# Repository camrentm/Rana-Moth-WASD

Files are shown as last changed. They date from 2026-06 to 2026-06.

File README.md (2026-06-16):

# The Rana Labs Moth (WASD Version)

WASD version of [Rana Labs'](https://github.com/rana-sylvatica) Moth, a foldable leverless controller.

<div style="display: flex; gap: 10px;">
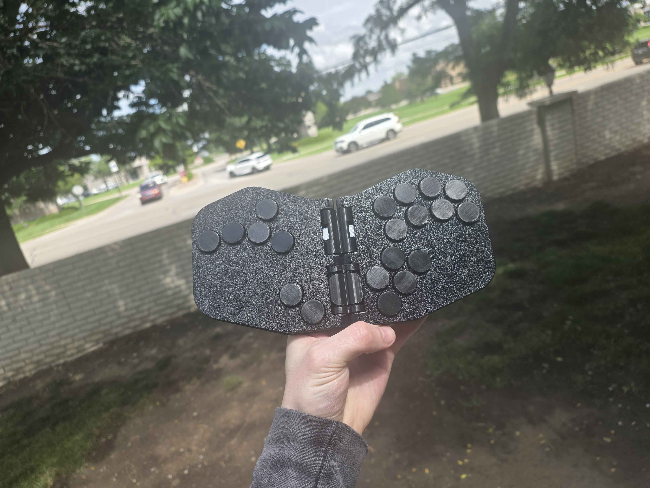
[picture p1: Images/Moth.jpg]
Moth open
    
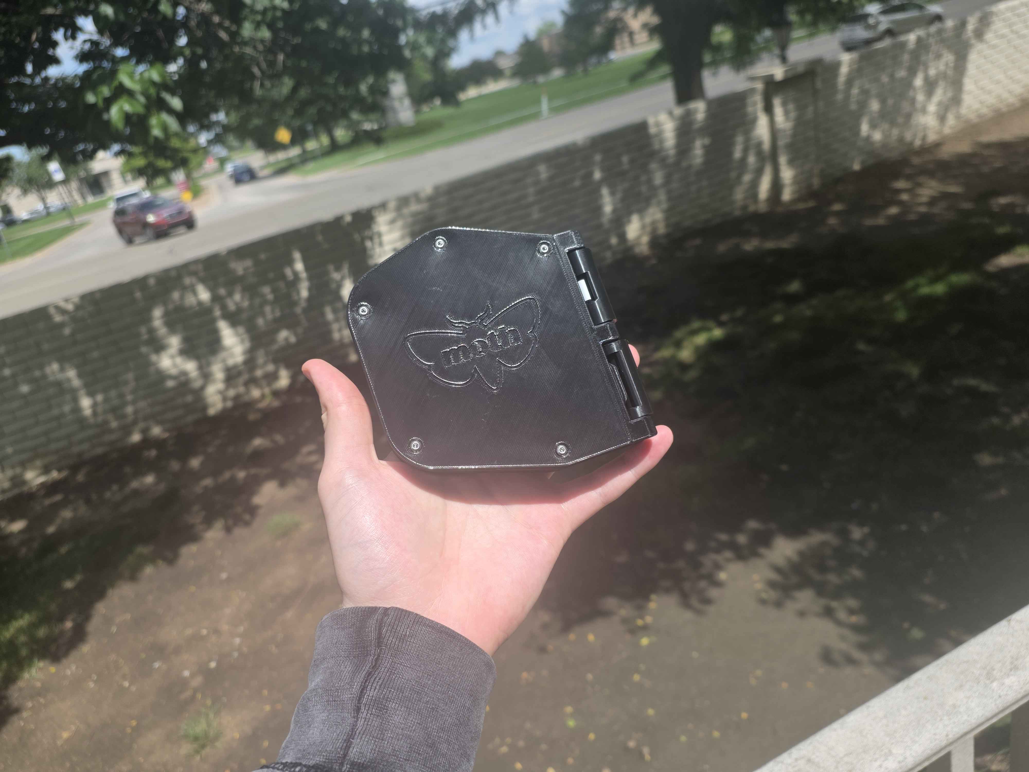
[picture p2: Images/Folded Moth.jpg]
Moth folded
    
</div>

---

## Components

I printed the entire shell and hinges in **Bambu Lab Matte PLA** (any PLA should work, though build quality feel may vary).

- **Mainboard:** RP2040 integrated directly onto the left custom PCB. The right side connects via ribbon cable.
- **Switches:** Any Kailh Choc low-profile switch. Must be low-profile (standard height switches won't fit).
- **USB-C:** [QuRB](https://github.com/rana-sylvatica/rana-tadpole/tree/main/PCBs/Breakout%20Board%20(QuRB)) by [Quark Works](https://github.com/quark-works) and Rana Labs, a USB-C breakout board with a ribbon cable port for solderless assembly.
- **Hardware:** M2 and M3 screws only. You'll need ten M3 heat inserts for the backplates, twelve M3×5/6mm bolts for the backplates and QuRB, and eight M2×4mm bolts for the mainboards.

---

## Assembly

The custom PCB eliminates all handwiring. The only soldering required is installing the hotswap sockets for the Choc switches.

The two halves connect via a 20-pin 0.5mm pitch ribbon cable. The QuRB connects to the left board via a 12-pin 0.5mm pitch ribbon cable for the USB-C port.

---

## Firmware

This build runs a custom fork of HayBox configured for the Moth layout. Find it at [camrentm/HayBox-Rana-Moth](https://github.com/camrentm/HayBox-Rana-Moth).

---

## Magnets

Strong magnets are essential since they're working against the spring force of every switch.

- **Size:** 6×3mm Neodymium, stacked 2 high per hole
- **Count:** 10 holes × 2 magnets = **20 magnets total**

The snap when closing is very satisfying and holds the Moth securely folded.

---

## Prism Ergonomic Mode

In the reverse-folded position, a lip on each hinge piece stops the wings from overfolding and creates a clean resting angle. The rounded hinge backs add friction to keep the Moth rigid in this position.

You can edit the lip width in the hinge model to adjust the fold angle to your preference.

---

## Notes

- **Button fit:** Buttons must sit flush with the face when depressed, or the halves won't close cleanly. Strong magnets may compensate for minor protrusion.
- **Hinge pin slot:** Left open in this design. The friction fit holds without caps, and it makes intentional pin removal much easier.

---

## Files

| Folder | Contents |
|---|---|
| `Shell/` | Top panels and backplates (STEP) |
| `Hinge and Buttons/` | Hinge upper/lower, hinge pin, and keycap models (STEP) |
| `Moth PCB/` | KiCad PCB project, schematics, and fabrication files |
| `DXF/` | PCB outlines and hole patterns |
| `Images/` | Build photos |

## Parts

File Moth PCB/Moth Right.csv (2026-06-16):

Designator | Footprint | Quantity | Value | LCSC Part #
J5 | XUNPU FPC-05F-20PH20 | 1 | FPC-05F-20PH20 | C2856803

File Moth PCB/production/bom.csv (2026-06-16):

Designator | Footprint | Quantity | Value | LCSC Part #
A | SW_Hotswap_Kailh_Choc_V1V2_THT | 1 | A
B | SW_Hotswap_Kailh_Choc_V1V2_THT | 1 | B
C1, C10, C2, C4 | 0402 | 4 | 1uF | C52923
C11, C12, C13, C14, C15, C16, C17, C3, C5, C6 | 0402 | 10 | 100nF | C1525
C7, C8 | 0402 | 2 | 22pF | C1555
C9 | 0402 | 1 | 10uF | C15525
C_DOWN | SW_Hotswap_Kailh_Choc_V1V2_THT | 1 | C Down
C_LEFT | SW_Hotswap_Kailh_Choc_V1V2_THT | 1 | C Left
C_RIGHT | SW_Hotswap_Kailh_Choc_V1V2_THT | 1 | C Right
C_UP | SW_Hotswap_Kailh_Choc_V1V2_THT | 1 | C Up
D1 | D_SOD-123 | 1 | Schottky Diode | C8598
D3 | 0805 | 1 | GREEN | C84256
DOWN | SW_Hotswap_Kailh_Choc_V1V2_THT | 1 | Down
J4 | FPC-05F-30PH20 | 1 | Left Ribbon
J5 | FPC-05F-30PH20 | 1 | Right Ribbon
L | SW_Hotswap_Kailh_Choc_V1V2_THT | 1 | L
LEFT | SW_Hotswap_Kailh_Choc_V1V2_THT | 1 | Left
LS | SW_Hotswap_Kailh_Choc_V1V2_THT | 1 | LS
MS | SW_Hotswap_Kailh_Choc_V1V2_THT | 1 | MS
MX | SW_Hotswap_Kailh_Choc_V1V2_THT | 1 | MX
MY | SW_Hotswap_Kailh_Choc_V1V2_THT | 1 | MY
R | SW_Hotswap_Kailh_Choc_V1V2_THT | 1 | R
R10, R11 | 0402 | 2 | 1k | C11702
R4 | 0402 | 1 | 470 | C25117
R5 | 0603 | 1 | 5.6k | C23189
R6 | 0603 | 1 | 10k | C25804
R7 | 0402 | 1 | 10k | C25744
R8, R9 | 0603 | 2 | 27 | C25190
RIGHT | SW_Hotswap_Kailh_Choc_V1V2_THT | 1 | Right
START | SW_Hotswap_Kailh_Choc_V1V2_THT | 1 | Start
SW1 | SW_SPST_SKQG_WithStem | 1 | Boot | C202424
U1 | SOT-23 | 1 | XC6206 | C5446
U2 | FPC-SMD_X05A26H12G | 1 | X05A26H12G | C519263
U3 | RP2040-QFN-56 | 1 | RP2040 | C2040
U4 | SOIC-8_5.23x5.23mm_P1.27mm | 1 | W25Q128JVS | C97521
UP | SW_Hotswap_Kailh_Choc_V1V2_THT | 1 | Up
X | SW_Hotswap_Kailh_Choc_V1V2_THT | 1 | X
Y | SW_Hotswap_Kailh_Choc_V1V2_THT | 1 | Y
Y1 | Crystal_SMD_3225-4Pin_3.2x2.5mm | 1 | 12MHz | C9002
Z | SW_Hotswap_Kailh_Choc_V1V2_THT | 1 | Z

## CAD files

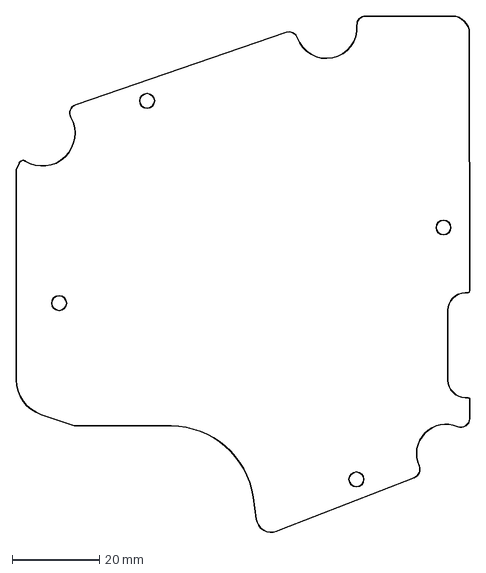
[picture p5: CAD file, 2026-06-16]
DXF/Reworked Left PCB.dxf
104.0 x 118.5 mm

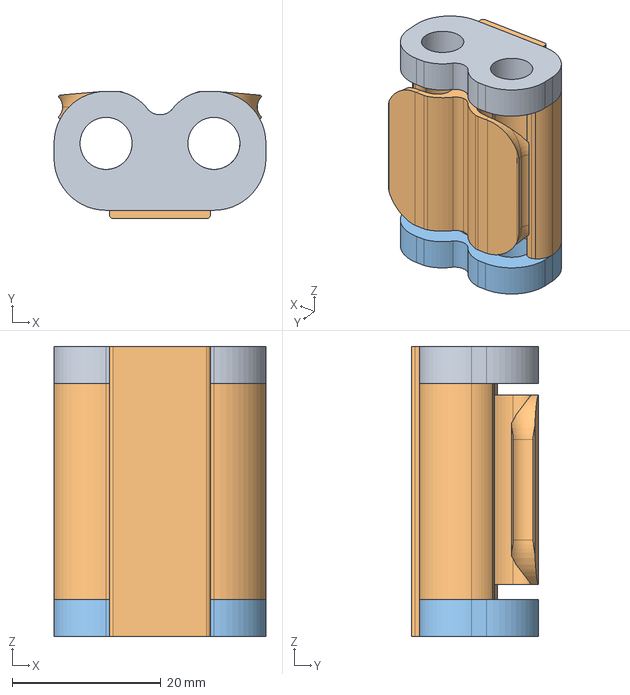
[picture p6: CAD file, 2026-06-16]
Hinge and Buttons/Hinge Lower.step
28.5 x 17.1 x 39.0 mm

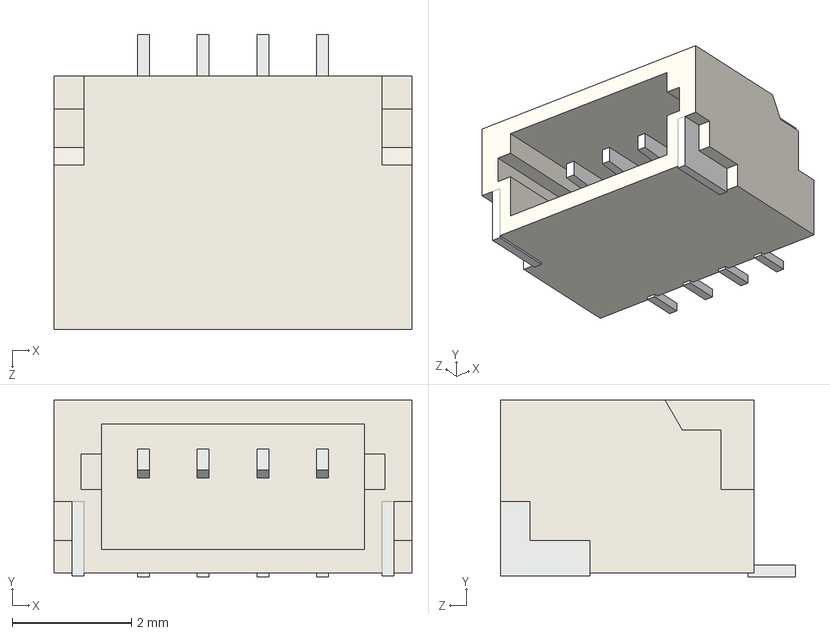
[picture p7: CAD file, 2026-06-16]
Moth PCB/qw-footprints/qw-footprints/JST-SM04B-SRSS-TB.STEP
6.00 x 2.96 x 4.95 mm

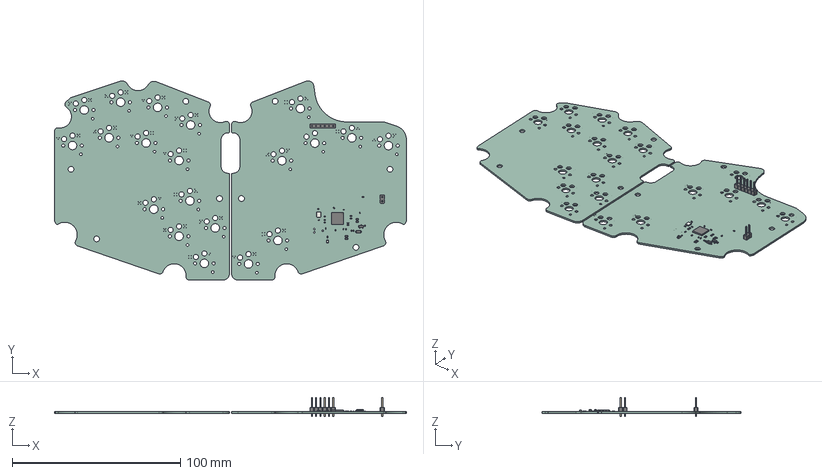
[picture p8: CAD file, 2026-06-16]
Moth PCB/Rana Tadpole PCB.step
209.1 x 118.4 x 11.5 mm
C_0402_1005Metric x 17
R_0603_1608Metric x 4
R_0402_1005Metric x 4
SOT_23
QFN-56-1EP_7x7mm_Pitch0.4mm
D_SOD_123
PinHeader_1x02_P254mm_Vertical
PinHeader_1x06_P254mm_Vertical
LED_0805_2012Metric
Crystal_SMD_3225-4Pin_3.2x2.5mm
Moth_PCB_1
Moth_PCB_2

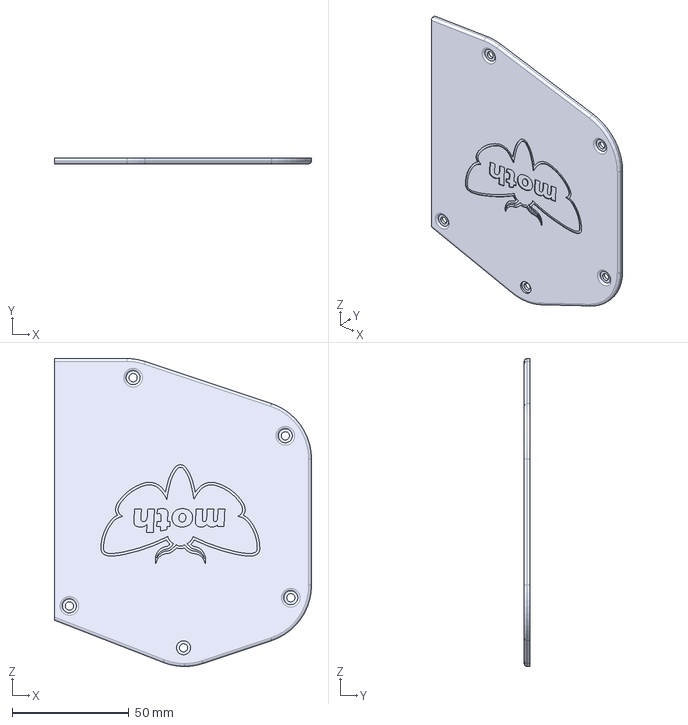
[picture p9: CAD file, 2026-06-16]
Shell/Moth Backplate Left.step
110.0 x 2.40 x 131.8 mm

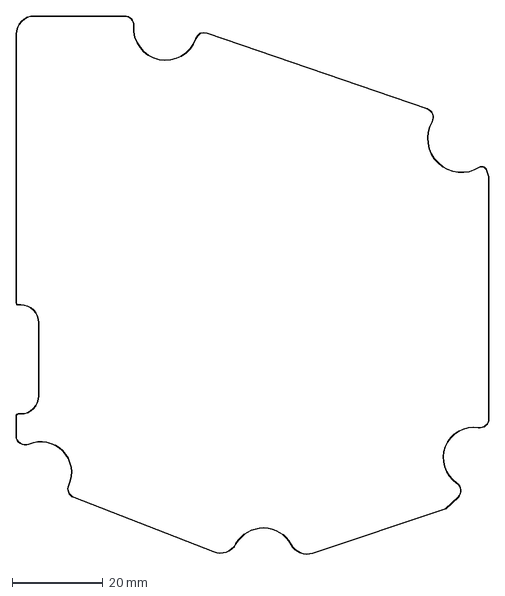
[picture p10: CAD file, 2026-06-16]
DXF/Right PCB.dxf
104.0 x 118.7 mm

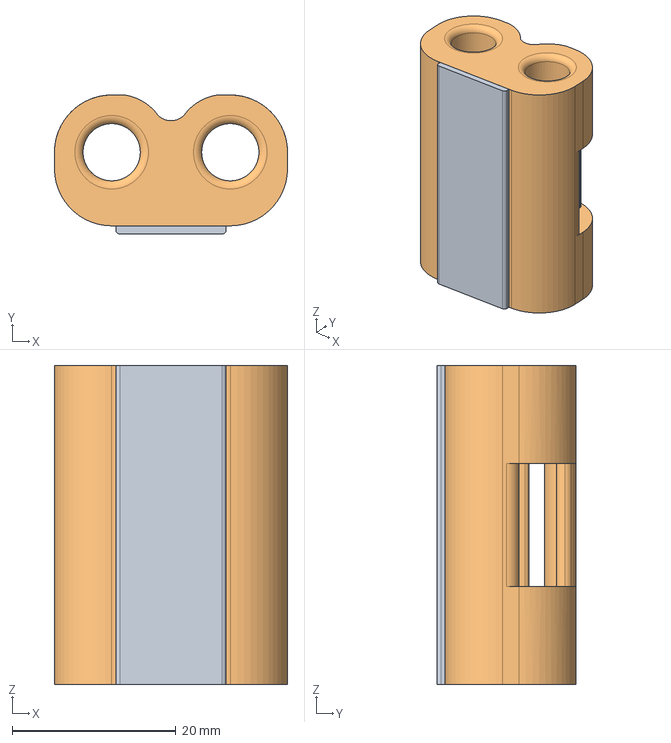
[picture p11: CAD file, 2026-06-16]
Hinge and Buttons/Hinge Upper.step
28.5 x 17.0 x 39.0 mm

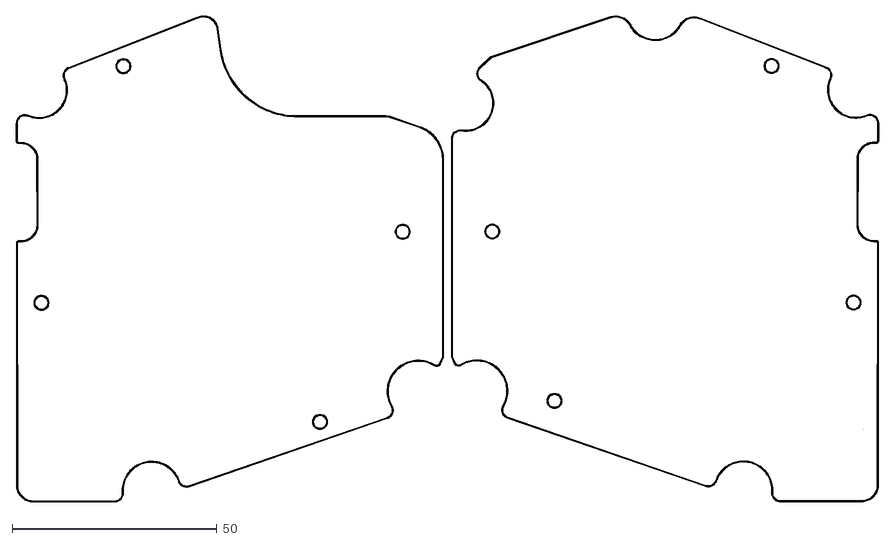
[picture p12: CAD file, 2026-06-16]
Moth PCB/Moth-Edge_Cuts.dxf
210.4 x 118.6

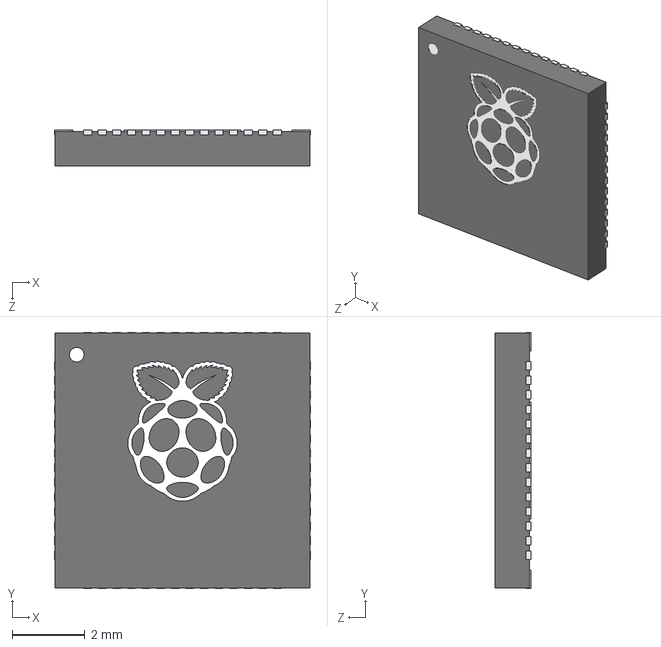
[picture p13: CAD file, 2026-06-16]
Moth PCB/qw-footprints/qw-footprints/RP2040_QFN_PACKAGE.STEP
7.02 x 7.02 x 1.00 mm

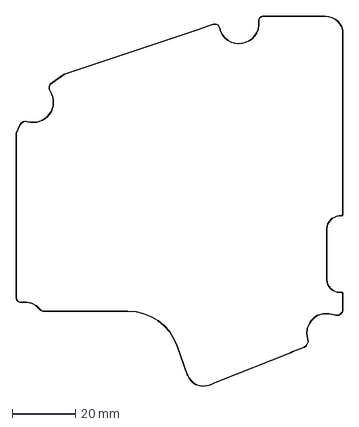
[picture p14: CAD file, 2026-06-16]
DXF/Left PCB.dxf
103.0 x 116.8 mm

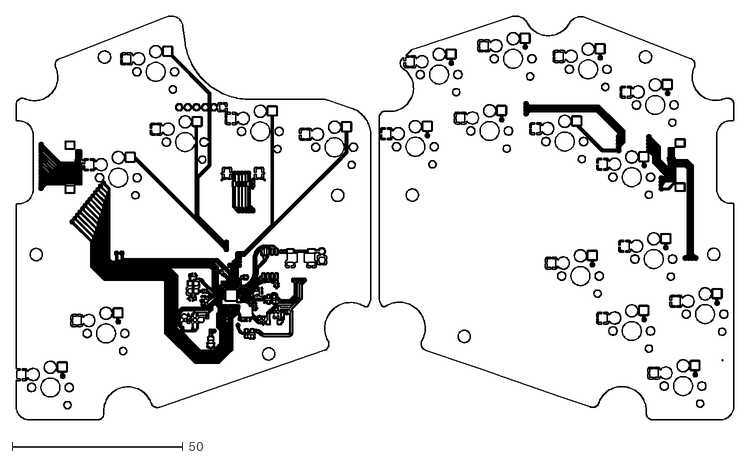
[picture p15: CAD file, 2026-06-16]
Moth PCB/Moth-F_Cu.dxf
210.0 x 118.2

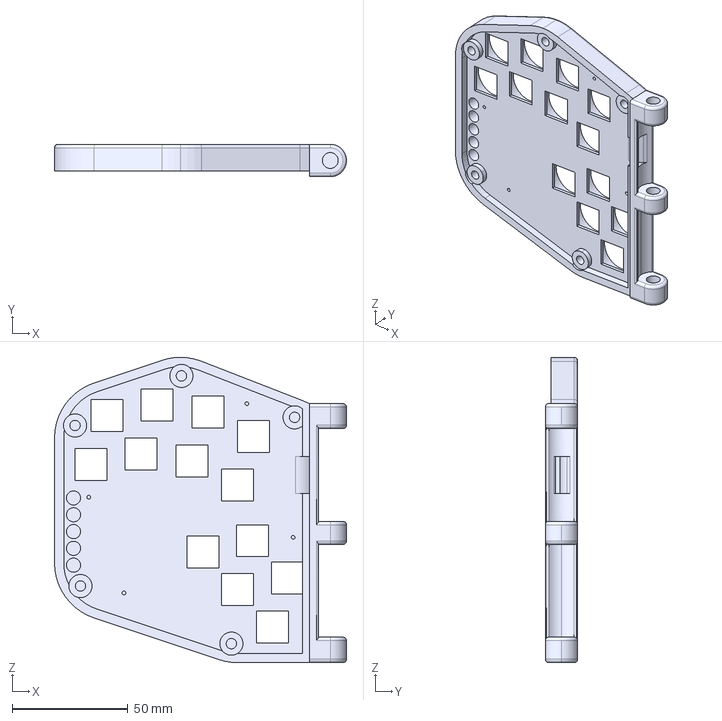
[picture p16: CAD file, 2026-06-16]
Shell/Moth Top Right.step
126.0 x 14.0 x 131.8 mm

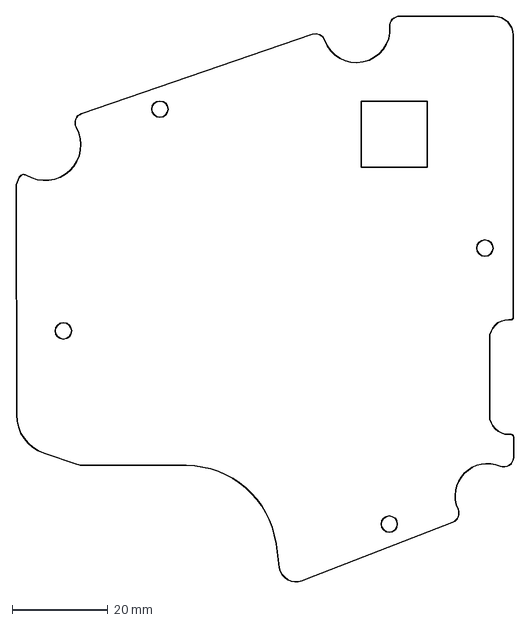
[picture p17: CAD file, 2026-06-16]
DXF/MX Move.dxf
104.0 x 118.5 mm

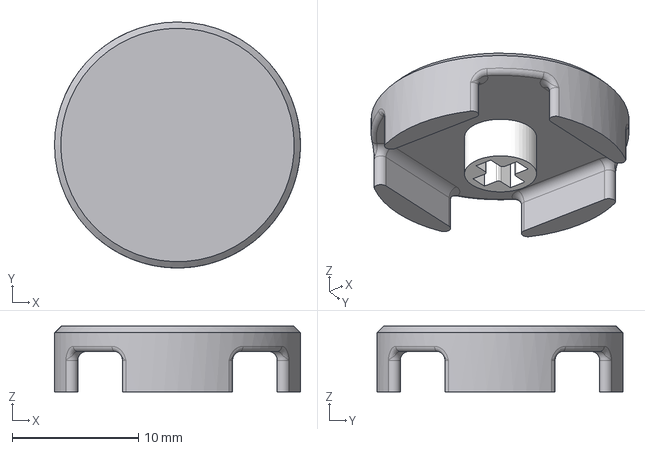
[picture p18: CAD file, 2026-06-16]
Hinge and Buttons/Choc v2 Keycaps.step
19.5 x 19.5 x 5.20 mm

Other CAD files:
Shell/Moth Backplate Right.step
Shell/Moth Top Left.step
DXF/Left PCB - Holes.dxf
Hinge and Buttons/Hinge Pin.step
DXF/Right PCB - Holes.dxf
Hinge and Buttons/Choc v1 Keycaps.step
Moth PCB/Moth-B_Mask.dxf
Moth PCB/Moth-B_Paste.dxf
Moth PCB/Moth-B_Silkscreen.dxf
Moth PCB/Moth-F_Mask.dxf
Moth PCB/Moth-F_Paste.dxf
Moth PCB/Moth-F_Silkscreen.dxf
Shell/Moth Top Left Rev 2.step

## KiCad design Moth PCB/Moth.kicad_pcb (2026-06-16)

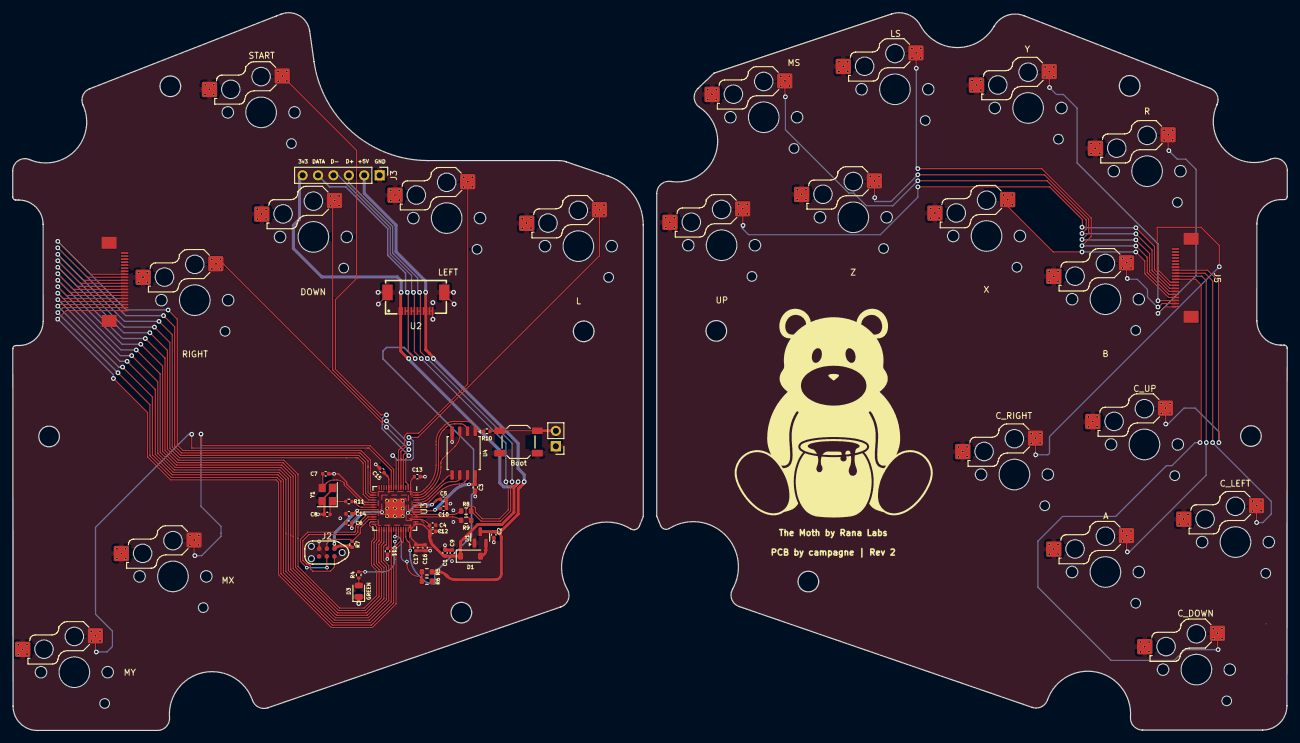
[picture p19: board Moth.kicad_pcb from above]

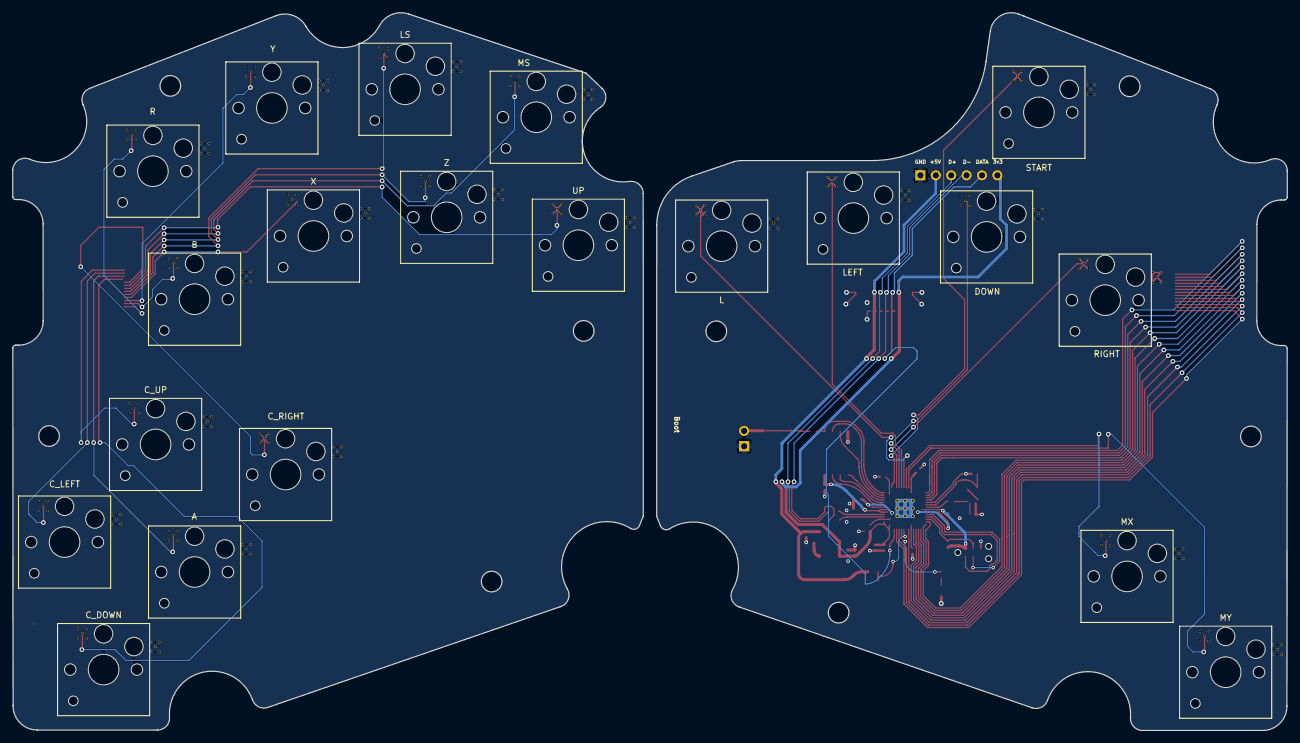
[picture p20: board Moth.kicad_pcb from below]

Board: 2 copper layers, 210.2 x 118.4 mm, 58 parts (20 on the bottom side), 59 nets.

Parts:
A: A; SW_Hotswap_Kailh_Choc_V1V2_THT
B: B; SW_Hotswap_Kailh_Choc_V1V2_THT
C1, C2, C4, C10: 1uF; C_0402_1005Metric
C3, C5, C6, C11, C12, C13, C14, C15, C16, C17: 100nF; C_0402_1005Metric
C7, C8: 22pF; C_0402_1005Metric
C9: 10uF; C_0402_1005Metric
C_DOWN: C Down; SW_Hotswap_Kailh_Choc_V1V2_THT
C_LEFT: C Left; SW_Hotswap_Kailh_Choc_V1V2_THT
C_RIGHT: C Right; SW_Hotswap_Kailh_Choc_V1V2_THT
C_UP: C Up; SW_Hotswap_Kailh_Choc_V1V2_THT
D1: Schottky Diode; D_SOD-123
D3: GREEN; LED_0805_2012Metric
DOWN: Down; SW_Hotswap_Kailh_Choc_V1V2_THT
J1: Conn_01x02; PinHeader_1x02_P2.54mm_Vertical
J2: JTAG_TC2030; CON_TC2030_outlined
J3: DuPont Connector; PinHeader_1x06_P2.54mm_Vertical
J4: Left Ribbon; FPC-05F-30PH20
J5: Right Ribbon; FPC-05F-30PH20
L: L; SW_Hotswap_Kailh_Choc_V1V2_THT
LEFT: Left; SW_Hotswap_Kailh_Choc_V1V2_THT
LS: LS; SW_Hotswap_Kailh_Choc_V1V2_THT
MS: MS; SW_Hotswap_Kailh_Choc_V1V2_THT
MX: MX; SW_Hotswap_Kailh_Choc_V1V2_THT
MY : MY; SW_Hotswap_Kailh_Choc_V1V2_THT
R: R; SW_Hotswap_Kailh_Choc_V1V2_THT
R4: 470; R_0402_1005Metric
R5: 5.6k; R_0603_1608Metric
R6: 10k; R_0603_1608Metric
R7: 10k; R_0402_1005Metric
R8, R9: 27; R_0603_1608Metric
R10, R11: 1k; R_0402_1005Metric
RIGHT: Right; SW_Hotswap_Kailh_Choc_V1V2_THT
START: Start; SW_Hotswap_Kailh_Choc_V1V2_THT
SW1: Boot; SW_SPST_SKQG_WithStem
U1: XC6206; SOT-23
U2: X05A26H12G; FPC-SMD_X05A26H12G
U3: RP2040; RP2040-QFN-56
U4: W25Q128JVS; SOIC-8_5.23x5.23mm_P1.27mm
UP: Up; SW_Hotswap_Kailh_Choc_V1V2_THT
X: X; SW_Hotswap_Kailh_Choc_V1V2_THT
Y: Y; SW_Hotswap_Kailh_Choc_V1V2_THT
Y1: 12MHz; Crystal_SMD_3225-4Pin_3.2x2.5mm
Z: Z; SW_Hotswap_Kailh_Choc_V1V2_THT

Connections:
3vDiode: C1.2, C3.1, C9.1, C10.1, C11.1, C12.1, C13.1, C14.1, C15.1, C16.1, C17.1, D1.1 (K), J2.1 (VCC), J3.6, R7.1, U2.1, U2.2, U3.1 (IOVDD), U3.10 (IOVDD), U3.22 (IOVDD), U3.33 (IOVDD), U3.42 (IOVDD), U3.43 (ADC_AVDD), U3.44 (VREG_VIN), U3.48 (USB_VDD), U3.49 (IOVDD), U4.8 (VCC)
+1V1: C4.1, C5.1, C6.1, U3.23 (DVDD), U3.45 (VREG_VOUT), U3.50 (DVDD)
+5V: C2.2, J3.2, R5.1, U1.3 (VI), U2.9, U2.10
/D_+: R8.2, U3.47 (D+)
/D_-: R9.2, U3.46 (D-)
/XTAL_O: C8.2, R11.1, Y1.1
/~USB_BOOT: J1.2, R10.1, SW1.2
A: A.1, J5.11
A RIBBON: J4.10, U3.17 (GPIO14)
B: B.1, J5.2
B RIBBON: J4.19, U3.38 (GPIO26/ADC0)
CS: R10.2, U3.56 (QSPI_SS_N), U4.1 (~CS)
C_DN: C_DOWN.1, J5.10
C_DN RIBBON: J4.11, U3.18 (GPIO15)
C_LT: C_LEFT.1, J5.12
C_LT RIBBON: J4.9, U3.16 (GPIO13)
C_RT: C_RIGHT.1, J5.9
C_RT RIBBON: J4.12, U3.27 (GPIO16)
C_UP: C_UP.1, J5.13
C_UP RIBBON: J4.8, U3.15 (GPIO12)
D+: J3.3, R8.1, U2.7, U2.8
D-: J3.4, R9.1, U2.5, U2.6
DATA: J3.5, U2.3, U2.4, U3.40 (GPIO28/ADC2)
DOWN: DOWN.1, U3.5 (GPIO3)
GND: A.2, B.2, C1.1, C2.1, C3.2, C4.2, C5.2, C6.2, C7.1, C8.1, C9.2, C10.2, C11.2, C12.2, C13.2, C14.2, C15.2, C16.2, C17.2, C_DOWN.2, C_LEFT.2, C_RIGHT.2, C_UP.2, D3.1 (K), DOWN.2, J1.1, J2.5 (GND), J3.1, J4.7, J5.14, L.2, LEFT.2, LS.2, MS.2, MX.2, MY.2, R.2, R6.2, RIGHT.2, START.2, SW1.1, U1.1 (GND), U2.11, U2.12, U2.13, U2.14, U3.19 (TESTEN), U3.57 (GND), U4.4 (GND), UP.2, X.2, Y.2, Y1.2, Y1.4, Z.2
L: L.1, U3.7 (GPIO5)
LEFT: LEFT.1, U3.6 (GPIO4)
LS: J5.5, LS.1
LS RIBBON: J4.16, U3.31 (GPIO20)
M1: MX.1, U3.8 (GPIO6)
M2: MY.1, U3.9 (GPIO7)
MS: J5.7, MS.1
MS RIBBON: J4.14, U3.29 (GPIO18)
unnamed: D1.2 (A), U1.2 (VO)
unnamed: D3.2 (A), R4.2
PICO_LED: R4.1, U3.37 (GPIO25)
QSPI_CLK: U3.52 (QSPI_SCLK), U4.6 (CLK)
R: J5.1, R.1
R RIBBON: J4.20, U3.39 (GPIO27/ADC1)
RIGHT: RIGHT.1, U3.4 (GPIO2)
SD0: U3.53 (QSPI_SD0), U4.5 (DI(IO0))
SD1: U3.55 (QSPI_SD1), U4.2 (DO(IO1))
SD2: U3.54 (QSPI_SD2), U4.3 (IO2)
SD3: U3.51 (QSPI_SD3), U4.7 (IO3)
START: START.1, U3.2 (GPIO0)
SWCLK: J2.4 (SWCLK), U3.24 (SWCLK)
SWD: J2.2 (SWDIO), U3.25 (SWDIO)
UP: J5.8, UP.1
UP RIBBON: J4.13, U3.28 (GPIO17)
VBUS_SENSE: R5.2, R6.1, U3.36 (GPIO24)
X: J5.4, X.1
X RIBBON: J4.17, U3.32 (GPIO21)
XTAL_IN: C7.2, U3.20 (XTAL_IN), Y1.3
XTAL_OUT: R11.2, U3.21 (XTAL_OUT)
Y: J5.3, Y.1
Y RIBBON: J4.18, U3.34 (GPIO22)
Z: J5.6, Z.1
Z RIBBON: J4.15, U3.30 (GPIO19)
~RESET: J2.3 (~RST), R7.2, U3.26 (~RUN)

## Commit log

2026-06-16 Initial commit — Rana Moth WASD foldable keyboard
    Includes shell/hinge STEP models, KiCad PCB project, DXF outlines,
    build photos, BOM, and README.
    [Choc v1 Keycaps.step, Choc v2 Keycaps.step, Hinge Lower.step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]
2026-06-16 Clean up old files; update README with new images and file table
    Removes: DXFs/ (replaced by DXF/), PCB Files (WIP)/ (replaced by Moth PCB/),
    old STL/STEP duplicates, old images, and Read Me.txt.
    Updates README to reference new build photos and adds a files table.
    [Bottom Left.step, Bottom Right.step, Hinge Pin.STL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]
2026-06-16 Remove dead Amazon magnet link
